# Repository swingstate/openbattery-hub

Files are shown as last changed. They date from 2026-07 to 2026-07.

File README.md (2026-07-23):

# OpenBattery Hub

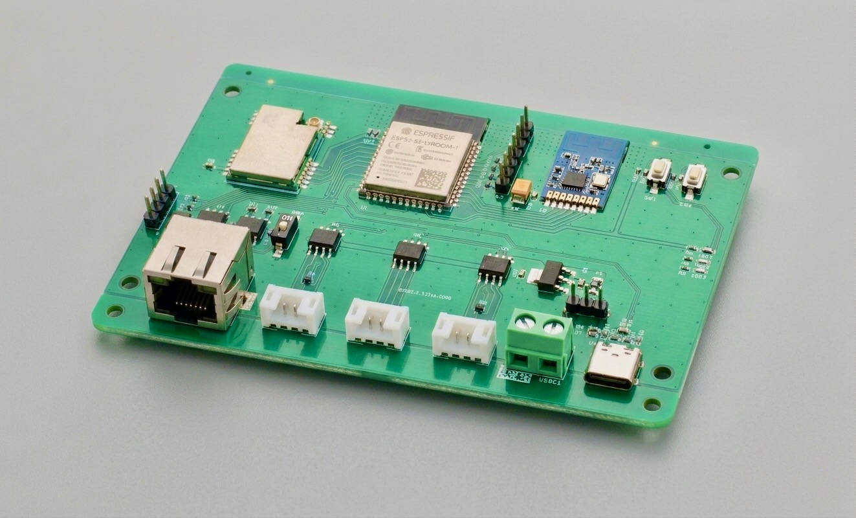
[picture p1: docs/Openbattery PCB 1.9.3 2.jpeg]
OpenBattery Hub PCB


OpenBattery Hub is a DIY-friendly, open-hardware ESP32-S3 IoT platform built
to work seamlessly with the open-source [OpenDTU-OnBattery](https://github.com/hoylabs/OpenDTU-OnBattery)
Project. It makes it easy to connect and monitor batteries, solar charge
controllers, and inverters — all in one compact device. Whether you're
building your own off-grid setup or just love tinkering with energy tech,
the Hub is designed to keep things simple, open, and fun to experiment with.

Built as an extensible, robust hardware platform for a variety of solar battery
systems, it aims to give developers and technicians a solid foundation
for building and adapting their own energy management solutions, behind
a single standardized interface for a range of different battery systems.

| Function | Specification |
|---|---|
| MCU | ESP32-S3 16MB |
| CAN Bus / RS-485 Interfaces | SN65HVD230DR / ISL3178EIBZ-T |
| VE.Direct Interfaces | 3x isolated, 4-PIN JST PH |
| Power & Programming | USB-C, onboard 5V-to-3.3V regulator, max. 1A |
| Dual Inverter Interface | Nordic NRF24L01+ (HM) / EByte CMT2300A (HMS/T) |

## What you can do with it

- Unlock the full potential of OpenDTU-OnBattery — all features fully supported
- Connect and control Hoymiles HM, HMS, and HMT inverters
- Connect and monitor up to 3 Victron MPPTs or 2 MPPTs and 1 Smartshunt
- Interface with popular batteries like Pylontech (CAN bus), JK-BMS, and Victron SmartShunt
- Optionally add a compact OLED display for real-time stats right on the device

**Example 1** — battery via Cat cable/CAN or JK RS485 adapter, with up to 3 MPPTs:

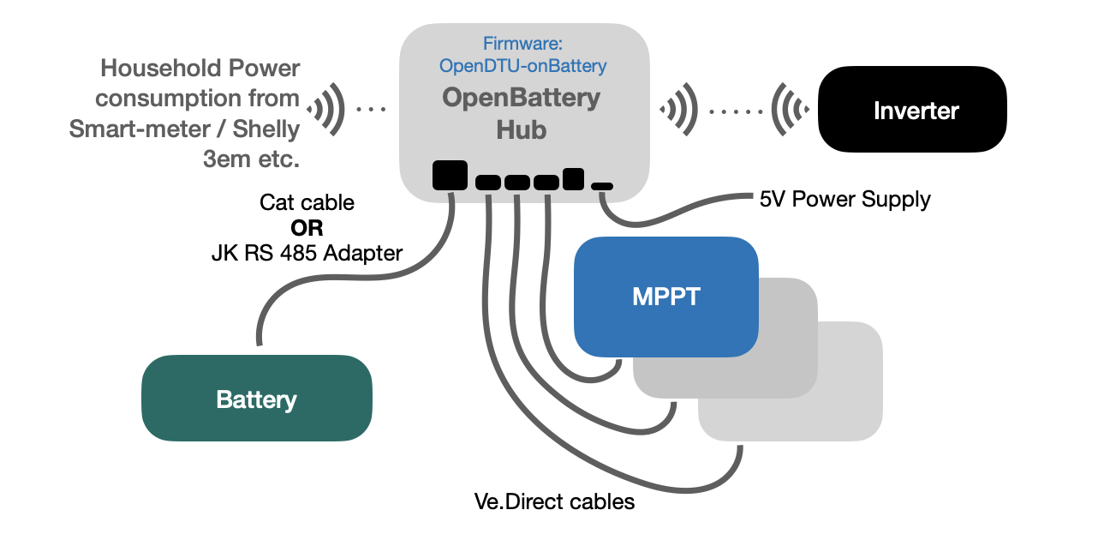
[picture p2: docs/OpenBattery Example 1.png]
Example setup: battery via CAN/RS485 with up to 3 MPPTs


**Example 2** — battery via Victron SmartShunt, with up to 2 MPPTs:

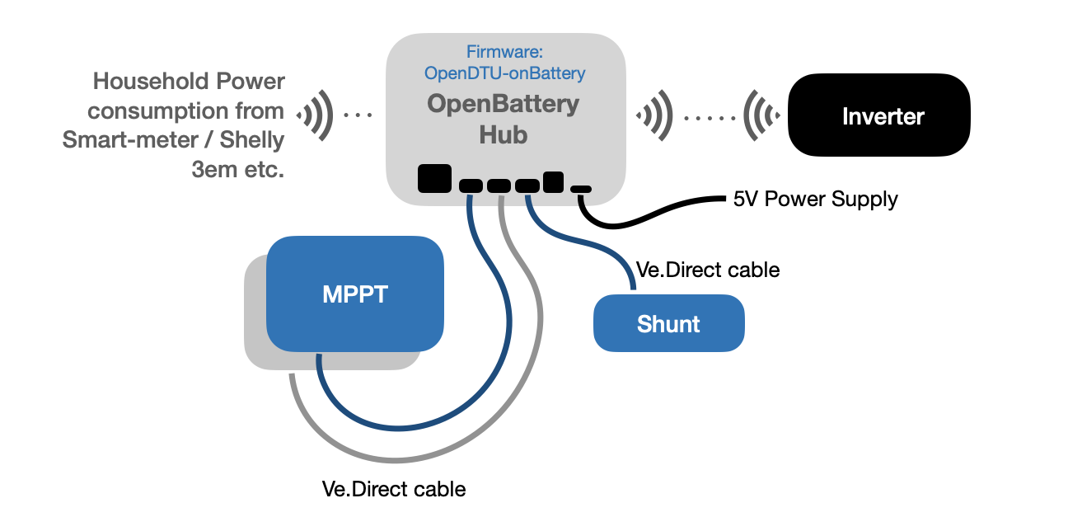
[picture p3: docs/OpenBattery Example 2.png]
Example setup: battery via SmartShunt with up to 2 MPPTs


A [detailed PCB view](docs/screenshot/2D_PCB%201.9.3_2026-07-22.png) (top-down, labeled layout) is also available.

## Enclosure

A 3D-printable case is included (see [`hardware/case`](hardware/case)).

<p>
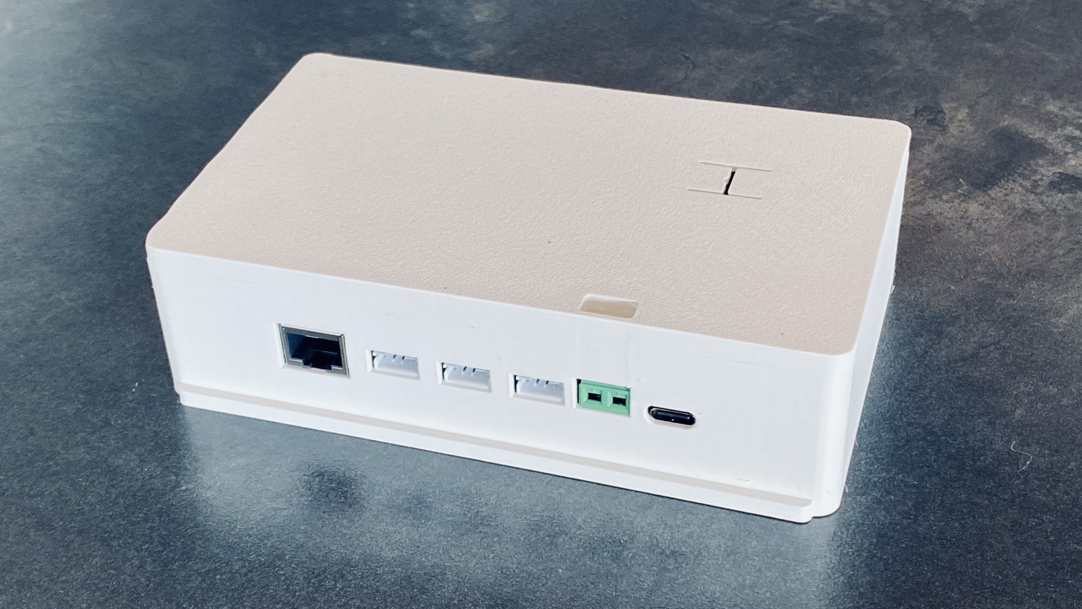
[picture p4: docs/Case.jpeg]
OpenBattery Hub in its 3D-printed case
  
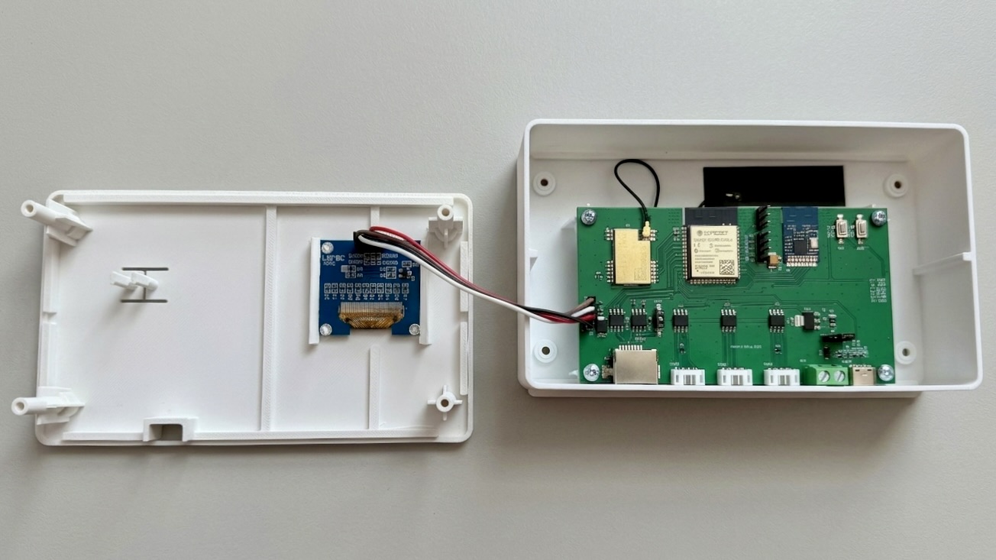
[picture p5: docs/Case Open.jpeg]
OpenBattery Hub case opened, board visible
  
</p>

## Status

- Hardware revision: **1.9.3**
- Field-tested with approx. 50 units

## Getting started

This board is bare hardware — by itself it does nothing. Everything it
does (talking to your inverters, batteries, and charge controllers, and
serving the web interface) comes from the **firmware**, which is a
separate open-source project: [**OpenDTU-OnBattery**](https://github.com/hoylabs/OpenDTU-OnBattery).
It is not included in this repository (see [License](#license) below)
and is not preinstalled — you flash it onto the board yourself before
first use.

1. **Flash the firmware.** Connect the board to your computer via
   USB-C and flash OpenDTU-OnBattery onto it. Instructions are in the
   [OpenDTU-OnBattery documentation](https://opendtu-onbattery.net/);
   the project also explains what OpenDTU-OnBattery is and how it
   works in general, independent of this specific board.
2. **Power it up.** Plug a 5V / 2A USB-C power supply into the board's
   USB-C port.
3. **Connect to its Wi-Fi hotspot.** After booting, the board creates
   its own Wi-Fi network named `OpenDTU-xxxxxx`. Connect to it with the
   default password `OpenDTU42`.
4. **Open the web interface.** With a browser, go to `192.168.4.1` and
   follow the on-screen setup. Be sure to pick the configuration
   profile that matches your hardware setup (which battery type, how
   many MPPTs, etc.) — the manual linked below lists the profile for
   each supported setup.
5. **Wire up your solar gear.** Connect your batteries, MPPT charge
   controllers, and/or inverter to the board's ports according to the
   profile you selected.

Full specifications, port pinouts, and wiring diagrams for common setups
(Pylontech CAN, JK-BMS RS485, Victron SmartShunt, multi-MPPT), plus the
optional OLED/serial header pinout, are documented in
[`docs/Openbattery Hub - Datasheet & Manual.pdf`](docs/Openbattery%20Hub%20-%20Datasheet%20%26%20Manual.pdf).

## Repository layout

```
hardware/
  schematics/   schematic exports (PDF)
  pcb/          PCB layout exports (PDF/PNG)
  bom/          Bill of Materials
  fabrication/  Pick-and-Place data and other assembly files
  gerber/       Gerber/drill files for fabrication
  case/         3D-printable enclosure files
  source/       editable EasyEDA/Altium source files (Complete Source, see hardware/source/README.md)
docs/           datasheet/manual, photos, additional documentation
```

## License

The hardware design files in this repository are licensed under the
**CERN Open Hardware Licence Version 2 - Strongly Reciprocal (CERN-OHL-S v2)**.

See [LICENSE](LICENSE) for the full licence text and [NOTICE.md](NOTICE.md)
for the required notice, source location, and scope (including what is
*not* covered — e.g. firmware and the project name/logo).

Firmware is **not** part of this repository. This board is designed to run
[OpenDTU-OnBattery](https://github.com/hoylabs/OpenDTU-OnBattery), an
independent open-source project licensed under GPL-3.0.

## Disclaimer

This is an open-source, hobbyist-grade hardware project, provided **"as
is"**, without warranty of any kind, express or implied — including, but
not limited to, fitness for a particular purpose or merchantability (see
[LICENSE](LICENSE) section 6, "Disclaimer and Liability", for the full
disclaimer of warranty and limitation of liability that governs the
design files).

This board is intended to be wired into battery and solar/PV systems,
which involve real electrical, fire, and chemical hazards (e.g. Li-ion
battery packs, DC bus voltages). Building, modifying, and operating it is
entirely **at your own risk**. The author(s) and contributors accept
**no liability** for any damage, injury, data loss, or other harm arising
from the use, misuse, or malfunction of this design, whether built from
the files in this repository or from boards manufactured elsewhere.

- This is not a certified or listed product (no CE/UL/etc. certification is claimed).
- Verify all wiring against your specific battery/inverter/charge-controller documentation before connecting anything.
- Have any mains or high-voltage work done or checked by a qualified electrician; follow the safety instructions and local regulations that apply to your battery and PV equipment.
- If you're not comfortable assessing these risks yourself, don't build or operate this board.

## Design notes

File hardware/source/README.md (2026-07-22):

# Source (editable design files)

- `ProPrj_OpenBattery Hub 1.9.3_2026-07-22.epro2` — the complete EasyEDA
  Pro project export (schematic, PCB layout, routing, footprints,
  symbols, board configuration). This is the "Complete Source" as
  defined in CERN-OHL-S v2 section 1.9 — open it in
  [EasyEDA Pro](https://easyeda.com/) (Import Project) to view or modify
  the schematic and PCB layout, including component placement and
  routing.
- `Altium_OpenBattery Hub 1.9.3_2026-07-22.zip` — Altium Designer export
  of the same design (`Schematic.schdoc`, `PCB 1.9.3.pcbdoc`), provided
  as an alternative editable format for those who prefer Altium over
  EasyEDA.
- `Netlist_Schematics_*.enet` / `Netlist_PCB_*.enet` — plain-text netlist
  exports (components, footprints, supplier/manufacturer part
  references, connectivity) for reference and tooling; derivable from
  the project files above.

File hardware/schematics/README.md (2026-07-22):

# Schematics

- `SCH_Schematics 1.9.3_2026-07-22.pdf` — schematic export, rev. 1.9.3

The editable schematic source is not yet included — see
[`hardware/source`](../source).

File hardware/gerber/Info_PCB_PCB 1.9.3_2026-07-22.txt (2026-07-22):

Project Title: 		OpenBattery Hub 1.9.3
Borard Title: 		Board1
PCB Title: 		PCB 1.9.3
Time: 		2026-07-22 20:09:50

Borard Size: 		106.5mm x 62.275mm
Layers: 		Total 22, Copper 2

Devices: 		38
Footprints: 		27
Components: 		Total 67,Top Layer 67,Bottom Layer 0
Pads: 		Total 279, Top Side Table Stick 241,Bottom Side Table Stick 0,Metallized Hole 38, Nonmetallic Hole 0
Nets: 		Total 68, Unrouted 1
Test Point: 		Nets Total 68, Has Testpoint Nets 0, Testpoint Coverage 0%
 		Total 0, Top Side Testpoints 0, Bottom Side Testpoints 0

Slot Region: 		6
Vias: 		Total 489, Through Vias 489, Blind Or Buried Vais 0
CopperAreas: 		14
Length of Tracks: 		2101.34mm

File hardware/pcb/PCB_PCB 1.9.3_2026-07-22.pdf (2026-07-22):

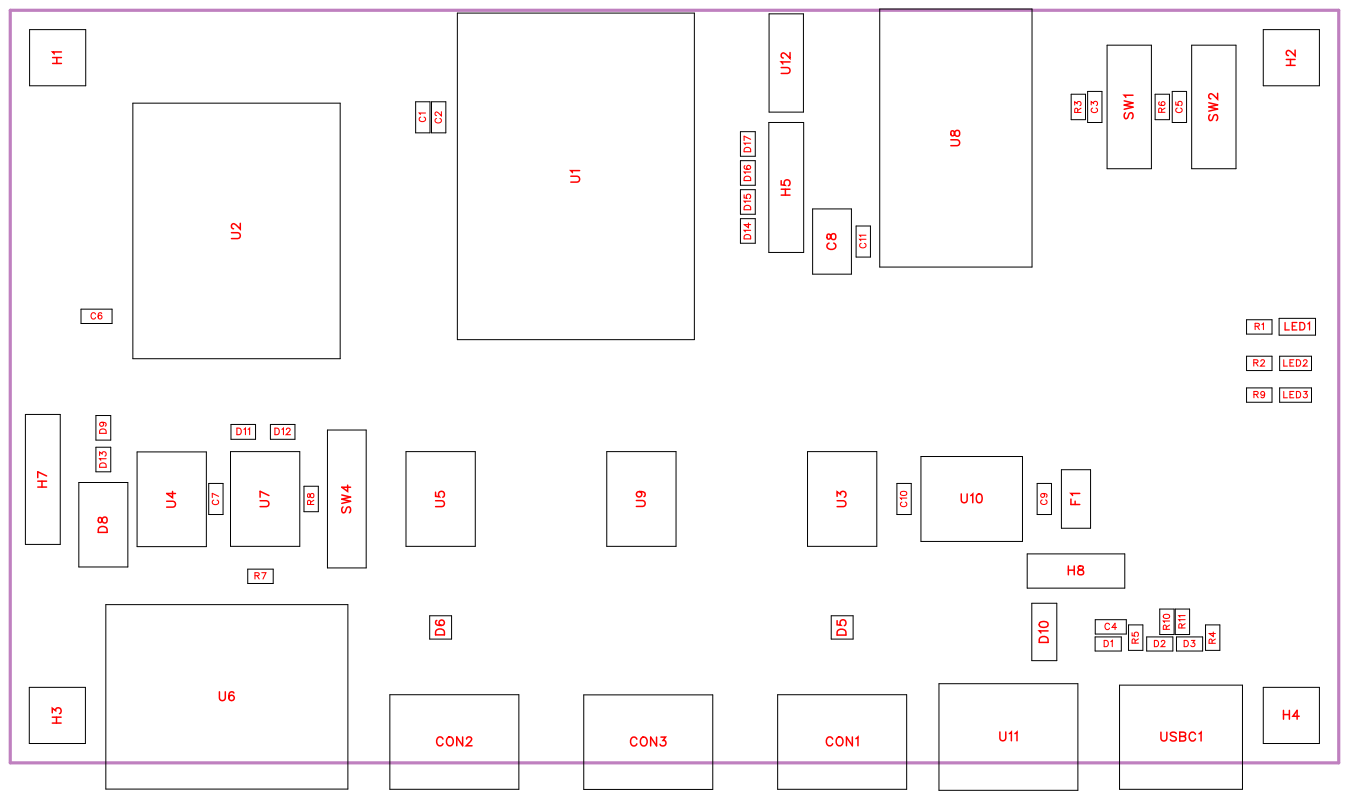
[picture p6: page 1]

No. | Quantity | Comment | Designator | Footprint | Value | Manufacturer Part | Manufacturer | Supplier Part | Supplier
1 | 1 | 22uF | C1 | C0402_4 | | GRM155R60 J226ME11D | muRata(村田 ) | C415703 | LCSC
2 | 7 | 100nF | C2,C3,C4,C5,C6,C7,C11 | C0402_4 | | CL05B104K O5NNNC | SAMSUNG( ) 三星 | C1525 | LCSC
3 | 1 | 100uF | C8 | CASE-B_353 1 | | TAJB107K00 6RNJ | Kyocera AVX | C16133 | LCSC
4 | 2 | 10uF | C9,C10 | C0402_4 | | CL05A106M Q5NUNC | SAMSUNG( 三星 ) | C15525 | LCSC
5 | 3 | PH-4AW_C7 22777 | CON1,CON2,CON3 | CONN-TH_P H-4AW_C72 2777_3 | | PH-4AW | CAX | C722777 | LCSC
6 | 3 | LESD5D5.0C T1G | D1,D2,D3 | SOD-523_L1 .2-W0.8-LS1. 6-BI_4 | | LESD5D5.0C T1G | LRC(乐山无 线电 ) | C383211 | LCSC
7 | 2 | TPD4E004D RYR | D5,D6 | SON-6_L1.5-W1.0-P0.50-BL_4 | | TPD4E004D RYR | TI(德州仪器 ) | C97503 | LCSC
8 | 1 | SMLVT3V3 | D8 | SMB_L4.6-W 3.6-LS5.3-R D_3 | | SMLVT3V3 | ST(意法半导 体) | C283619 | LCSC
9 | 8 | DESD3V3E1 BL-7B | D9,D11,D12,D13,D14,D15, D16,D17 | X1-DFN1006 -2_L1.0-W0.6 -P0.65-BI_2 | | DESD3V3E1 BL-7B | DIODES( 美 ) 台 | C461817 | LCSC
10 | 1 | LMBR220FT 1G | D10 | SOD-123F_L 2.7-W1.7-LS 3.7-RD-1_5 | | LMBR220FT 1G | LRC(乐山无 ) 线电 | C559074 | LCSC
11 | 1 | Resettable Fuse | F1 | F1206_3 | | Resettable Fuse | JKSEMI(金开 盛) | C355572 | LCSC
12 | 4 | PZ254V-11-0 1P | H1,H2,H3,H4 | HDR-TH_1P-P2.54-V-M_2 | | PZ254V-11-0 1P | XFCN(兴飞 ) | C492400 | LCSC
13 | 2 | Header-Male -2.54_1x4 | H5,H7 | HDR-TH_4P-P2.54-V-M_3 | | B-2100S04P-A110 | Ckmtw(灿科 盟) | C124378 | LCSC
14 | 1 | Header-Male -2.54_1x3 | H8 | HDR-TH_3P-P2.54-V-M-1 _3 | | 2.54-1*3P 针 | BOOMELE( 博穆精密 ) | C49257 | LCSC
15 | 1 | BLUE | LED1 | LED0402-R-RD_3 | | BLUE | EVERLIGHT( ) 亿光 | C131223 | LCSC
16 | 1 | GREEN | LED2 | LED0402-RD _GREEN_3 | | GREEN | TOGIALED( ) 统佳 | C273601 | LCSC
17 | 1 | White | LED3 | LED0402-RD _WHITE_3 | | TJ-S1005SW 4TGLCCW-A 5 | TOGIALED( 统佳 ) | C273604 | LCSC
18 | 3 | 1.5k | R1,R2,R9 | R0402_3 | | 0402WGF15 01TCE | UNI-ROYAL( 厚声 ) | C25867 | LCSC
19 | 3 | 10k | R3,R6,R8 | R0402_3 | | 0402WGF10 02TCE | UNI-ROYAL( 厚声 ) | C25744 | LCSC
20 | 2 | 5.1k | R4,R5 | R0402_3 | | 0402WGF51 01TCE | UNI-ROYAL( 厚声 ) | C25905 | LCSC

21 | 1 | 120 | R7 | R0402_3 | 0402WGF12 00TCE | UNI-ROYAL( 厚声 ) | C25079 | LCSC
22 | 2 | 22 | R10,R11 | R0402_3 | 0402WGF22 0JTCE | UNI-ROYAL( ) 厚声 | C25092 | LCSC
23 | 2 | TS-1101-C- W | SW1,SW2 | SW-SMD_L6 .0-W3.3-LS8. 0_3 | TS-1101-C- W | XKB Connect ivity(中国星坤 ) | C318938 | LCSC
24 | 1 | DSIC01LSG ET | SW4 | SW-SMD_D SIC01LSGET _3 | DSIC01LSG ET | YE | C54948 | LCSC
25 | 1 | ESP32-S3-W ROOM-1-N1 6R8 | U1 | WIRELM-SM D_ESP32-S3 -WROOM-1_ 4 | ESP32-S3-W ROOM-1-N1 6R8 | ESPRESSIF( 乐鑫 ) | C2913202 | LCSC
26 | 1 | E49-900M20 S | U2 | WIRELM-SM D_E49-400M 20S_3 | E49-900M20 S | EBYTE(亿佰 特) | C2965510 | LCSC
27 | 3 | ADUM1201A R-RL7 | U3,U5,U9 | SOIC-8_L4.9 -W3.9-P1.27-LS6.0-BL_3 | ADUM1201A R-RL7 | Analog Devices | C660257 | LCSC
28 | 1 | ISL3178EIBZ -T | U4 | SOIC-8_L4.9 -W3.9-P1.27-LS6.0-BL_3 | ISL3178EIBZ -T | RENESAS( 瑞萨)/IDT | C382015 | LCSC
29 | 1 | HC-RJ45-05 5-4 | U6 | RJ45-SMD_ HC-RJ45-05 5-4_5 | HC-RJ45-05 5-4 | HCTL(华灿天 禄) | C3000211 | LCSC
30 | 1 | SN65HVD23 0DR | U7 | SOIC-8_L4.9 -W3.9-P1.27-LS6.0-BL_3 | SN65HVD23 0DR | TI(德州仪器 ) | C12084 | LCSC
31 | 1 | E01-ML01S | U8 | WIRELM-SM D_E01-ML01 S_3 | E01-ML01S | EBYTE(亿佰 特) | C108546 | LCSC
32 | 1 | AMS1117-3. 3 | U10 | SOT-223-4_L 6.5-W3.5-P2. 30-LS7.0-BR _3 | AMS1117-3. 3 | UMW(友台半 导体 ) | C347222 | LCSC
33 | 1 | KF127-5.08-2P | U11 | CONN-TH_P 5.08_KF127-5.08-2P_3 | KF127-5.08-2P | KEFA(科发 ) | C474906 | LCSC
34 | 1 | HB-PH3-254 13PB2GOP | U12 | HDR-TH_3P-P2.54-V-M_3 | HB-PH3-254 13PB2GOP | HANBO(汉博 ) | C6332196 | LCSC
35 | 1 | TYPE-C-31-M-12 | USBC1 | USB-C_SMD -TYPE-C-31-M-12_3 | TYPE-C-31-M-12 | 韩国韩荣 | C165948 | LCSC

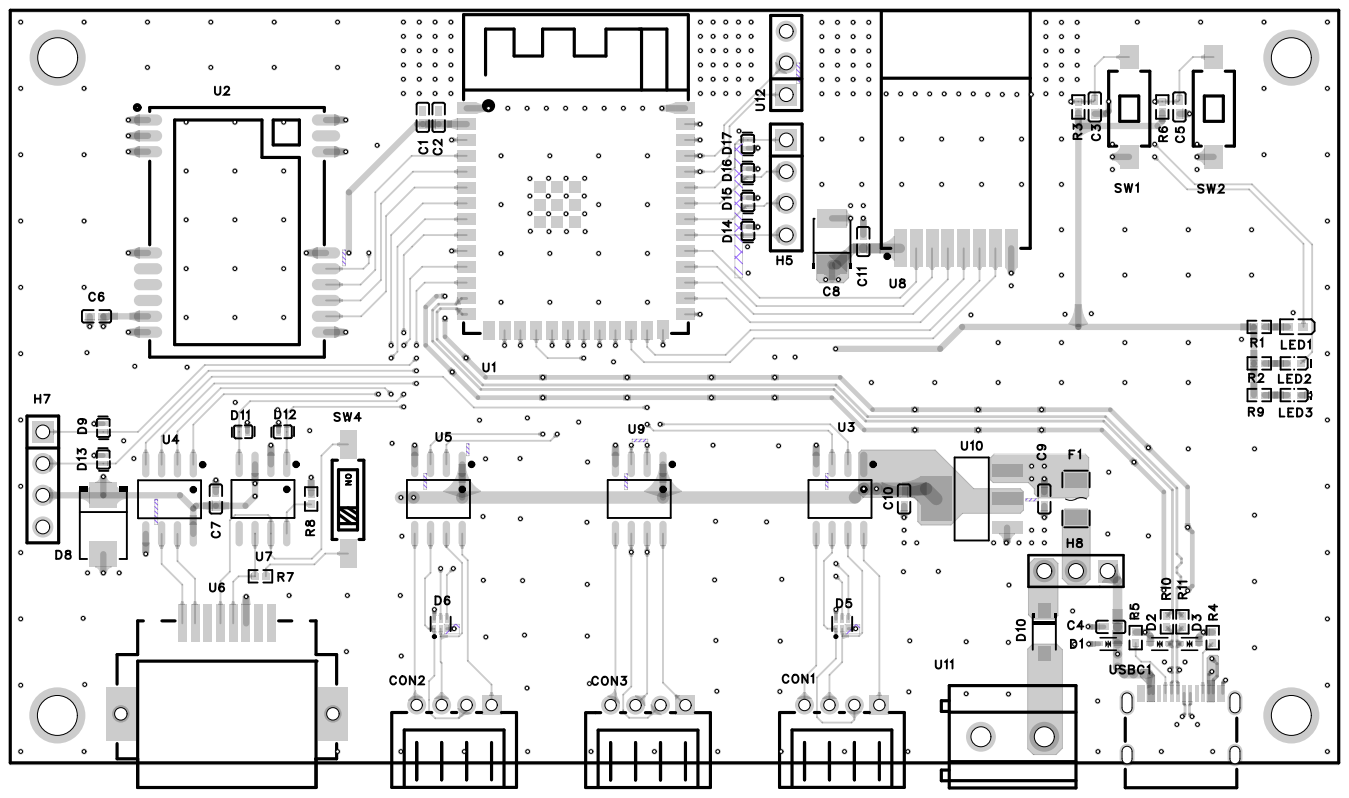
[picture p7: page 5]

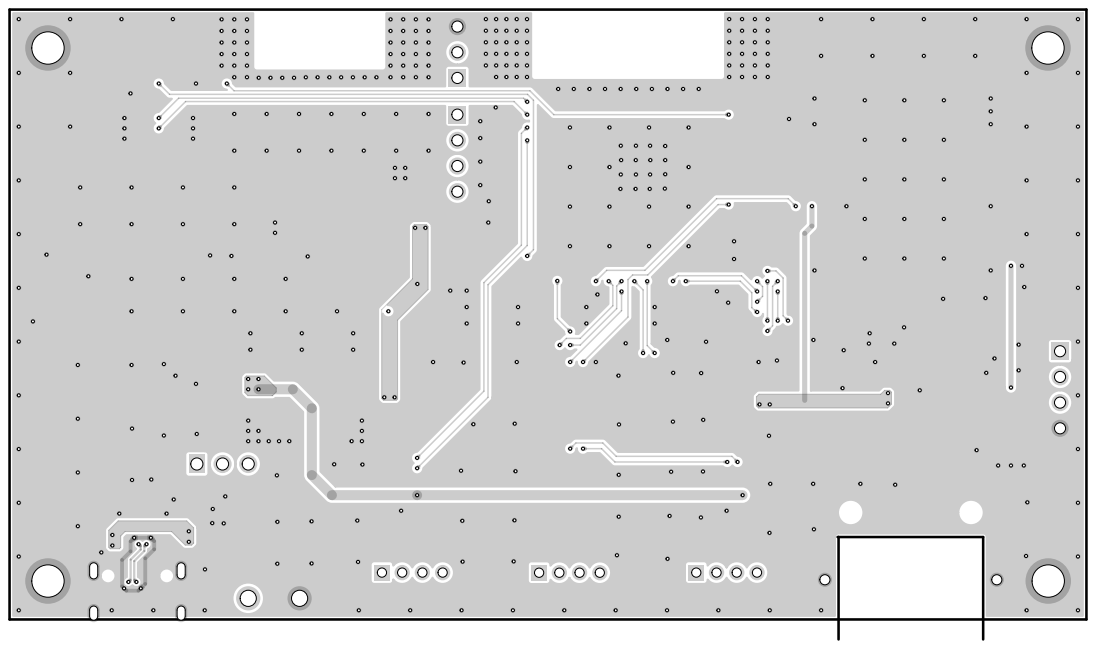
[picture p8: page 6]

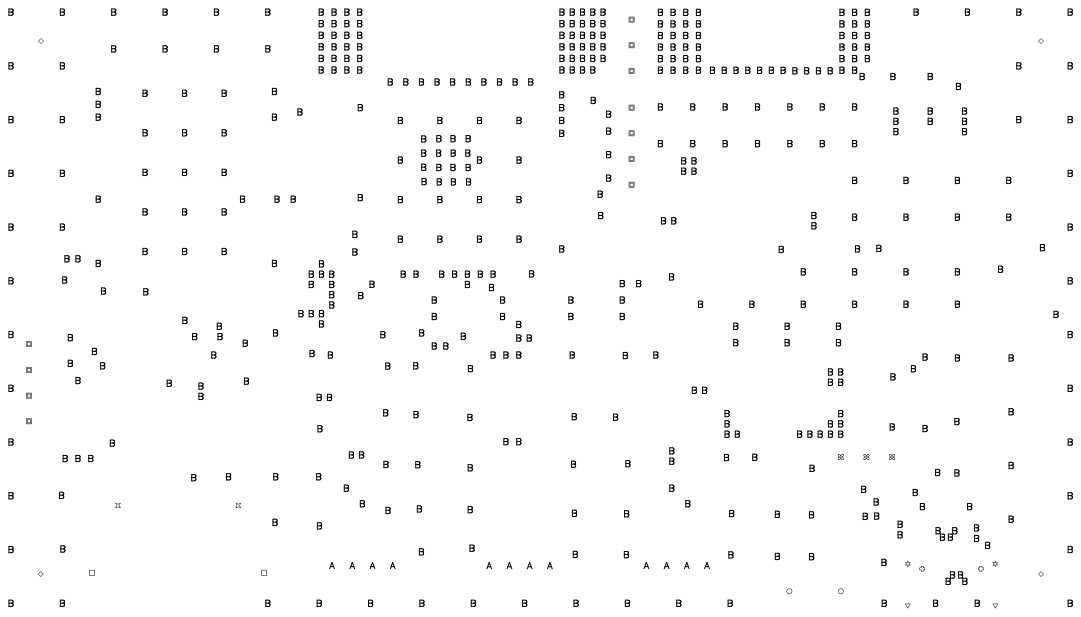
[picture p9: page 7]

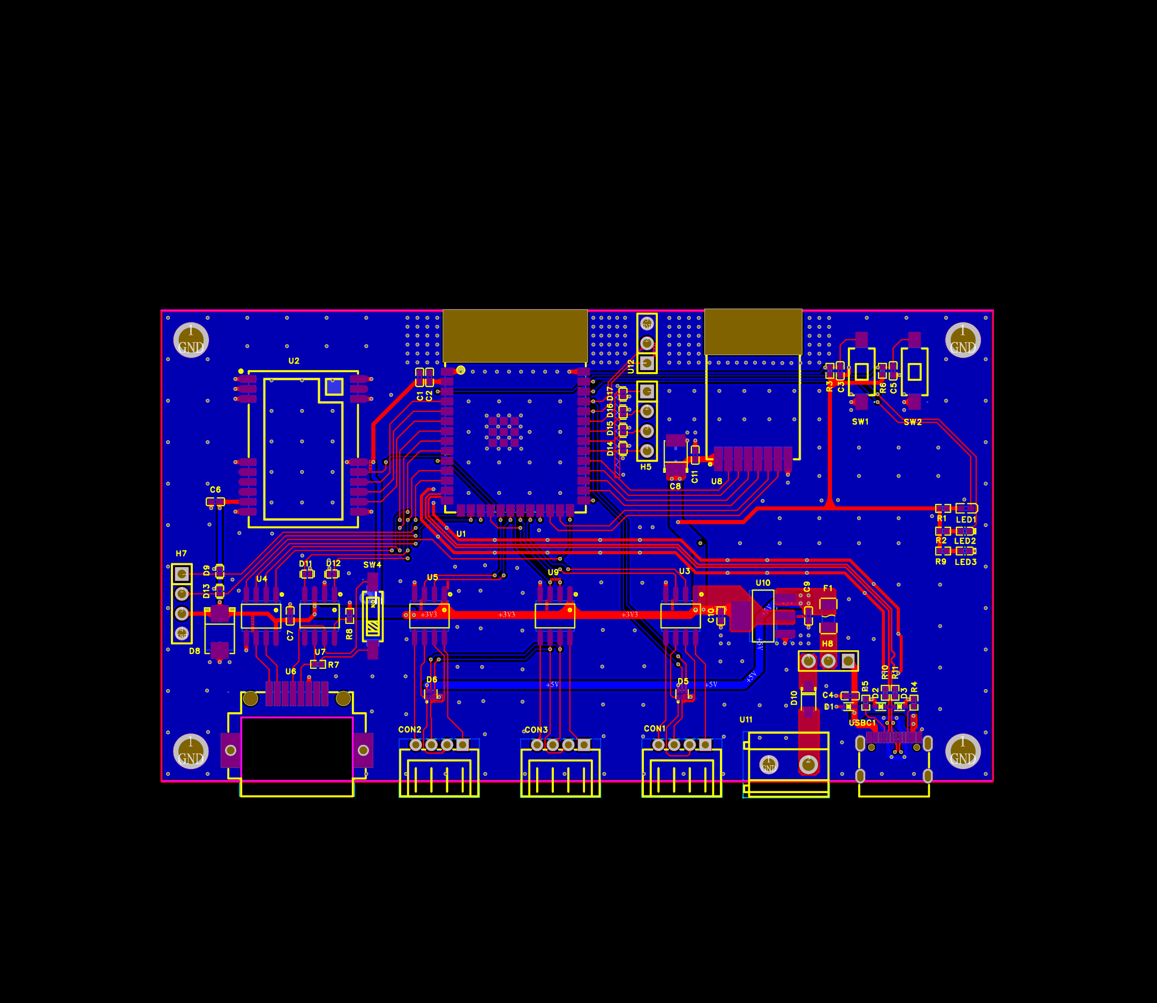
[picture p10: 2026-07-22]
hardware/pcb/PCB_PCB 1.9.3_2026-07-22.png

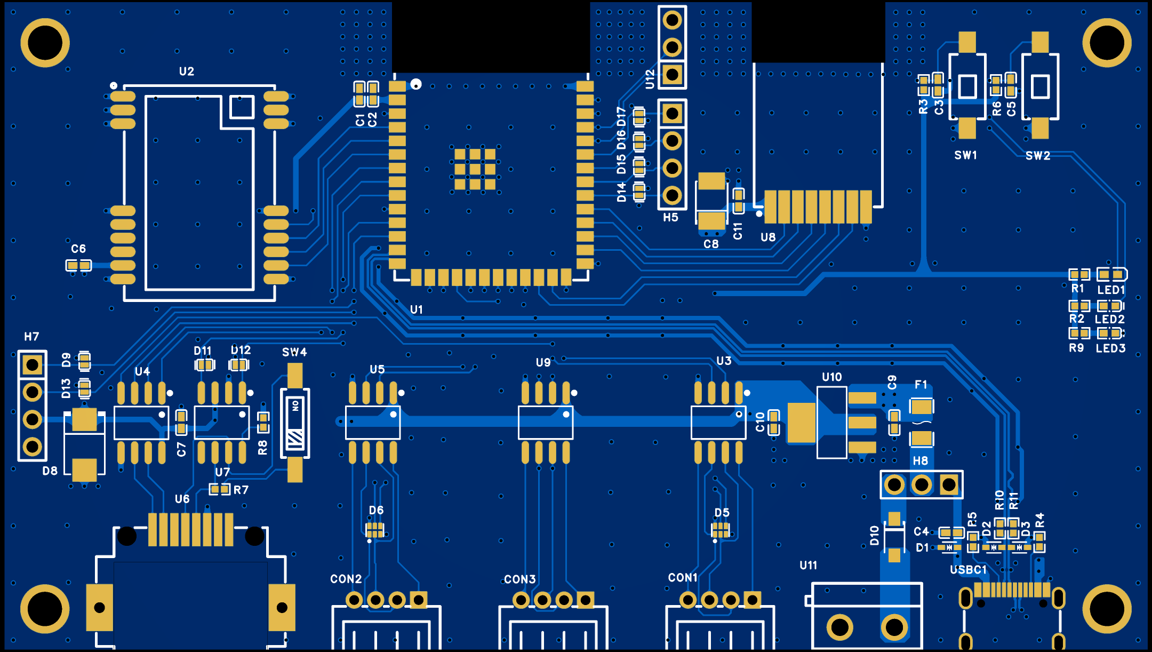
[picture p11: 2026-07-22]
docs/screenshot/2D_PCB 1.9.3_2026-07-22.png

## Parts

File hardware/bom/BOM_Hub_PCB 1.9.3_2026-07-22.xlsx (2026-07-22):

No. | Quantity | Comment | Designator | Footprint | Value | Manufacturer Part | Manufacturer | Supplier Part | Supplier
1 | 1 | 22uF | C1 | C0402_4 |  | GRM155R60J226ME11D | muRata(村田) | C415703 | LCSC
2 | 7 | 100nF | C2,C3,C4,C5,C6,C7,C11 | C0402_4 |  | CL05B104KO5NNNC | SAMSUNG(三星) | C1525 | LCSC
3 | 1 | 100uF | C8 | CASE-B_3531 |  | TAJB107K006RNJ | Kyocera AVX | C16133 | LCSC
4 | 2 | 10uF | C9,C10 | C0402_4 |  | CL05A106MQ5NUNC | SAMSUNG(三星) | C15525 | LCSC
5 | 3 | PH-4AW_C722777 | CON1,CON2,CON3 | CONN-TH_PH-4AW_C722777_3 |  | PH-4AW | CAX | C722777 | LCSC
6 | 3 | LESD5D5.0CT1G | D1,D2,D3 | SOD-523_L1.2-W0.8-LS1.6-BI_4 |  | LESD5D5.0CT1G | LRC(乐山无线电) | C383211 | LCSC
7 | 2 | TPD4E004DRYR | D5,D6 | SON-6_L1.5-W1.0-P0.50-BL_4 |  | TPD4E004DRYR | TI(德州仪器) | C97503 | LCSC
8 | 1 | SMLVT3V3 | D8 | SMB_L4.6-W3.6-LS5.3-RD_3 |  | SMLVT3V3 | ST(意法半导体) | C283619 | LCSC
9 | 8 | DESD3V3E1BL-7B | D9,D11,D12,D13,D14,D15,D16,D17 | X1-DFN1006-2_L1.0-W0.6-P0.65-BI_2 |  | DESD3V3E1BL-7B | DIODES(美台) | C461817 | LCSC
10 | 1 | LMBR220FT1G | D10 | SOD-123F_L2.7-W1.7-LS3.7-RD-1_5 |  | LMBR220FT1G | LRC(乐山无线电) | C559074 | LCSC
11 | 1 | Resettable Fuse | F1 | F1206_3 |  | Resettable Fuse | JKSEMI(金开盛) | C355572 | LCSC
12 | 4 | PZ254V-11-01P | H1,H2,H3,H4 | HDR-TH_1P-P2.54-V-M_2 |  | PZ254V-11-01P | XFCN(兴飞) | C492400 | LCSC
13 | 2 | Header-Male-2.54_1x4 | H5,H7 | HDR-TH_4P-P2.54-V-M_3 |  | B-2100S04P-A110 | Ckmtw(灿科盟) | C124378 | LCSC
14 | 1 | Header-Male-2.54_1x3 | H8 | HDR-TH_3P-P2.54-V-M-1_3 |  | 2.54-1*3P针 | BOOMELE(博穆精密) | C49257 | LCSC
15 | 1 | BLUE | LED1 | LED0402-R-RD_3 |  | BLUE | EVERLIGHT(亿光) | C131223 | LCSC
16 | 1 | GREEN | LED2 | LED0402-RD_GREEN_3 |  | GREEN | TOGIALED(统佳) | C273601 | LCSC
17 | 1 | White | LED3 | LED0402-RD_WHITE_3 |  | TJ-S1005SW4TGLCCW-A5 | TOGIALED(统佳) | C273604 | LCSC
18 | 3 | 1.5kΩ | R1,R2,R9 | R0402_3 |  | 0402WGF1501TCE | UNI-ROYAL(厚声) | C25867 | LCSC
19 | 3 | 10kΩ | R3,R6,R8 | R0402_3 |  | 0402WGF1002TCE | UNI-ROYAL(厚声) | C25744 | LCSC
20 | 2 | 5.1kΩ | R4,R5 | R0402_3 |  | 0402WGF5101TCE | UNI-ROYAL(厚声) | C25905 | LCSC
21 | 1 | 120Ω | R7 | R0402_3 |  | 0402WGF1200TCE | UNI-ROYAL(厚声) | C25079 | LCSC
22 | 2 | 22Ω | R10,R11 | R0402_3 |  | 0402WGF220JTCE | UNI-ROYAL(厚声) | C25092 | LCSC
23 | 2 | TS-1101-C-W | SW1,SW2 | SW-SMD_L6.0-W3.3-LS8.0_3 |  | TS-1101-C-W | XKB Connectivity(中国星坤) | C318938 | LCSC
24 | 1 | DSIC01LSGET | SW4 | SW-SMD_DSIC01LSGET_3 |  | DSIC01LSGET | YE | C54948 | LCSC
25 | 1 | ESP32-S3-WROOM-1-N16R8 | U1 | WIRELM-SMD_ESP32-S3-WROOM-1_4 |  | ESP32-S3-WROOM-1-N16R8 | ESPRESSIF(乐鑫) | C2913202 | LCSC
26 | 1 | E49-900M20S | U2 | WIRELM-SMD_E49-400M20S_3 |  | E49-900M20S | EBYTE(亿佰特) | C2965510 | LCSC
27 | 3 | ADUM1201AR-RL7 | U3,U5,U9 | SOIC-8_L4.9-W3.9-P1.27-LS6.0-BL_3 |  | ADUM1201AR-RL7 | Analog Devices | C660257 | LCSC
28 | 1 | ISL3178EIBZ-T | U4 | SOIC-8_L4.9-W3.9-P1.27-LS6.0-BL_3 |  | ISL3178EIBZ-T | RENESAS(瑞萨)/IDT | C382015 | LCSC
29 | 1 | HC-RJ45-055-4 | U6 | RJ45-SMD_HC-RJ45-055-4_5 |  | HC-RJ45-055-4 | HCTL(华灿天禄) | C3000211 | LCSC
30 | 1 | SN65HVD230DR | U7 | SOIC-8_L4.9-W3.9-P1.27-LS6.0-BL_3 |  | SN65HVD230DR | TI(德州仪器) | C12084 | LCSC
31 | 1 | E01-ML01S | U8 | WIRELM-SMD_E01-ML01S_3 |  | E01-ML01S | EBYTE(亿佰特) | C108546 | LCSC
32 | 1 | AMS1117-3.3 | U10 | SOT-223-4_L6.5-W3.5-P2.30-LS7.0-BR_3 |  | AMS1117-3.3 | UMW(友台半导体) | C347222 | LCSC
33 | 1 | KF127-5.08-2P | U11 | CONN-TH_P5.08_KF127-5.08-2P_3 |  | KF127-5.08-2P | KEFA(科发) | C474906 | LCSC
34 | 1 | HB-PH3-25413PB2GOP | U12 | HDR-TH_3P-P2.54-V-M_3 |  | HB-PH3-25413PB2GOP | HANBO(汉博) | C6332196 | LCSC
35 | 1 | TYPE-C-31-M-12 | USBC1 | USB-C_SMD-TYPE-C-31-M-12_3 |  | TYPE-C-31-M-12 | 韩国韩荣 | C165948 | LCSC

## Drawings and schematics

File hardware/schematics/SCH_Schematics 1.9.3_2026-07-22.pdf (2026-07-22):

# ESP32-S3 MCU

## RESET

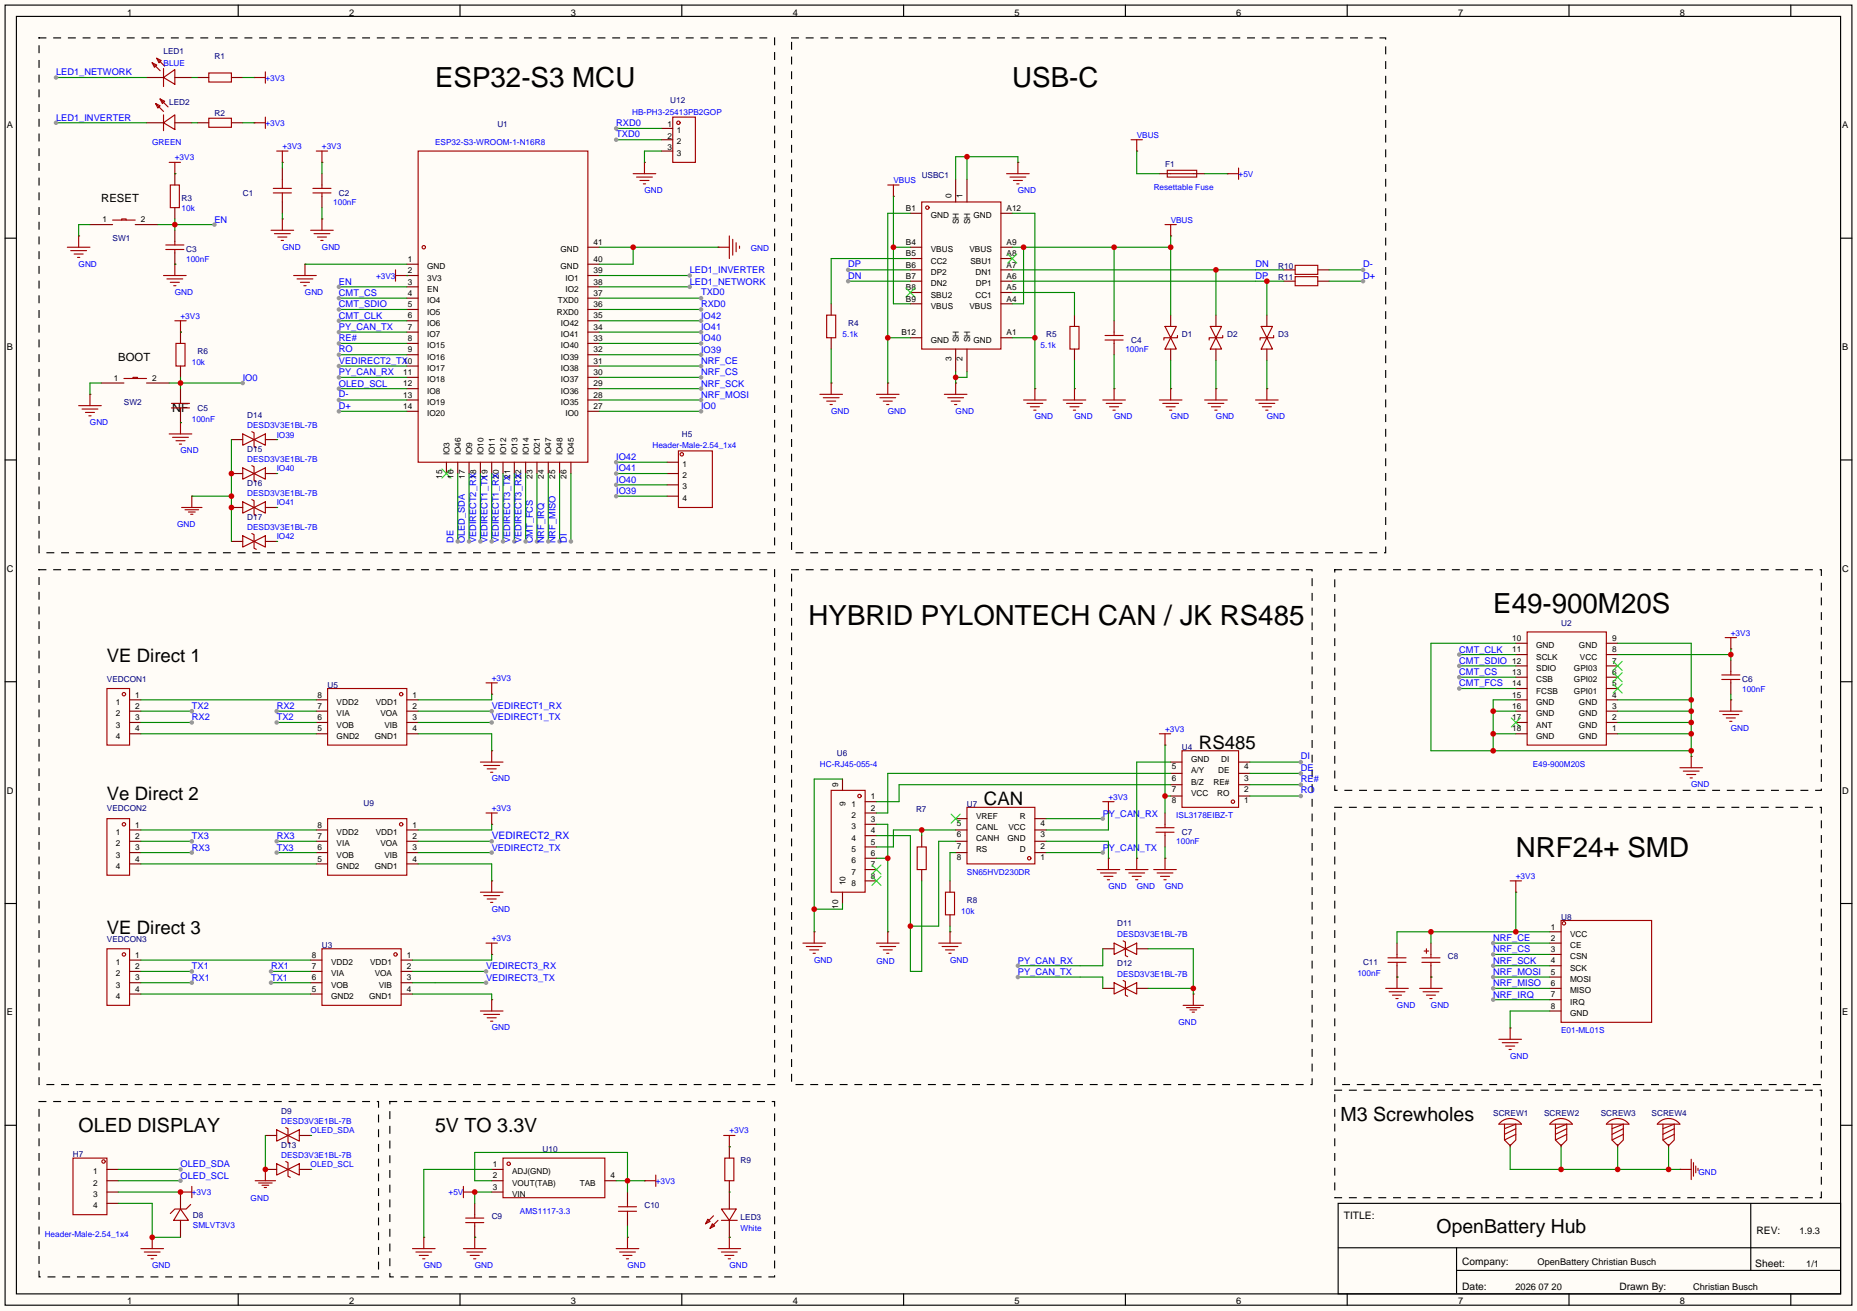
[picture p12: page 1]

HYBRID PYLONTECH CAN / JK RS485

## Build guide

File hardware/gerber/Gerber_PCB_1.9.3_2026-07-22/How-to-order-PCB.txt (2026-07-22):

How to Order PCB

Please refer to:
https://prodocs.easyeda.com/en/pcb/order-order-pcb/index.html

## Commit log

2026-07-22 OpenBattery Hub rev. 1.9.3 — initial public release under CERN-OHL-S v2
    [BOM_Hub_PCB 1.9.3_2026-07-22.xlsx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]
2026-07-22 Add PCB screenshot to README, refer to OpenDTU-OnBattery Project
2026-07-22 Add manual, product photos, and 3D-printable case files; expand README with manual content
2026-07-23 Use new PCB photo as README hero image, link 2D layout as detailed view
2026-07-23 Clarify supported inverters and battery systems in README
    Updated the README to clarify the supported inverter models and battery configurations.
2026-07-23 Add example wiring diagrams to What you can do with it section
